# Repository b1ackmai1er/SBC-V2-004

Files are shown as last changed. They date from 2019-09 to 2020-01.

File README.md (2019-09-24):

# SBC-V2-004
 Retrobrew Computers SBC-V2 development

 Updated design to include the following changes.

    Correction of reset circuit.
    Addition of speaker circuit.
    Add solder jumpers for bypassing DS1210.
    Move status LED to corner of board as per other ECB boards.
    Align serial connector pinout and functionality to SBC Z180 Mark IV
    Add max232 solder jumpers for TTL level output.
    Add onboard super capacitor.
    Incorporate ppide.
    Update to Kicad 5.
    Add jumper settings to silkscreen.
    Move reset switch to edge of board and remove reset jumper.
    Add jumpers to configure battery backup source.
    Add cpu clock divider to support MSX.
    Default to hard Kontron reset mode.

Other ideas to be considered:

    RAM access over ECB-BUS.
    Renumber all parts.

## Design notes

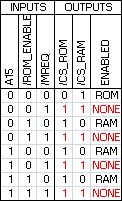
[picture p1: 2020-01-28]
logic.png

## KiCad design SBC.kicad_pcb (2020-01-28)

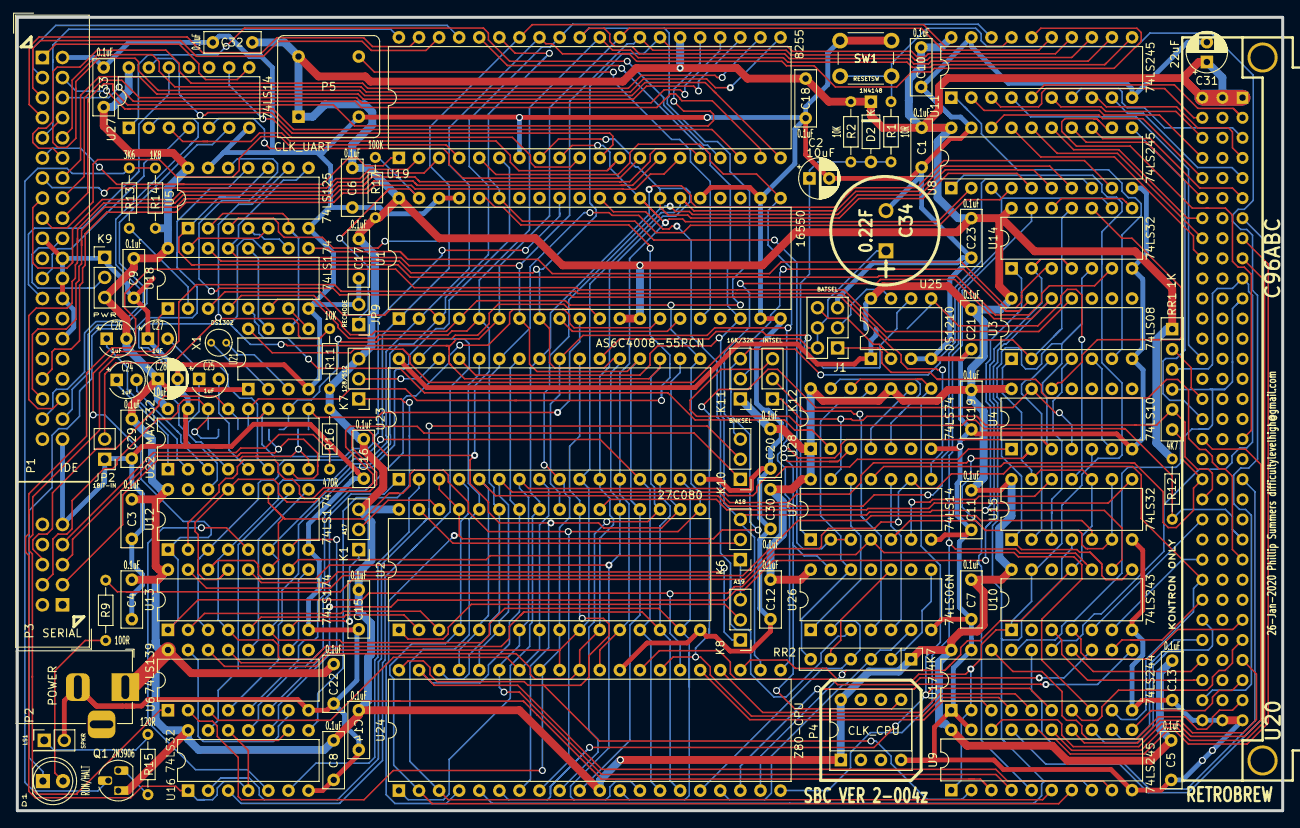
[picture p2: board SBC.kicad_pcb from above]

Board: 2 copper layers, 160.0 x 100.3 mm, 102 parts (0 on the bottom side), 203 nets.

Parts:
C1, C3, C4, C5, C6, C7, C8, C9, C10, C11, C12, C13, C14, C15, C16, C17, C18, C19, C20, C21, C22, C23, C29, C30, C32, C33: 0.1uF; C_Disc_D7.0mm_W2.5mm_P5.00mm
C2, C28: 10uF; CP_Radial_D5.0mm_P2.50mm
C24, C25, C26, C27: 1uF; CP_Radial_Tantal_D4.5mm_P2.50mm
C31: 22uF; CP_Radial_D5.0mm_P2.50mm
C34: 0.22F; SuperCap5
D1: RUN/HALT; LED_D5.0mm
D2: 1N4148; D_DO-35_SOD27_P7.62mm_Horizontal
J1: BATSEL; PinHeader_2x03_P2.54mm_Vertical
JP2: 1BIT-IN; PinHeader_1x02_P2.54mm_Vertical
JP3: RAMVCC; SolderJumper-2_P1.3mm_Open_RoundedPad1.0x1.5mm
JP4: RAMCS; SolderJumper-2_P1.3mm_Open_RoundedPad1.0x1.5mm
JP5: RXD; SolderJumper-2_P1.3mm_Open_RoundedPad1.0x1.5mm
JP6: CTS; SolderJumper-2_P1.3mm_Open_RoundedPad1.0x1.5mm
JP7: TXD; SolderJumper-2_P1.3mm_Open_RoundedPad1.0x1.5mm
JP8: RTS; SolderJumper-2_P1.3mm_Open_RoundedPad1.0x1.5mm
JP9: RECMODE; PinHeader_1x02_P2.54mm_Vertical
K1: A17; PinHeader_1x03_P2.54mm_Vertical
K6: A18; PinHeader_1x03_P2.54mm_Vertical
K7: 128/512; PinHeader_1x03_P2.54mm_Vertical
K8: A19; PinHeader_1x03_P2.54mm_Vertical
K9: PWR; PinHeader_1x03_P2.54mm_Vertical
K10: BNKSEL; PinHeader_1x03_P2.54mm_Vertical
K11: 16K/32K; PinHeader_1x03_P2.54mm_Vertical
K12: INTSEL; PinHeader_1x03_P2.54mm_Vertical
LS1: SPKR; PinHeader_2x01_P2.54mm_Vertical
P1: IDE; IDC-Header_2x20_P2.54mm_Vertical
P2: POWER; BarrelJack_Horizontal
P3: SERIAL; IDC-Header_2x05_P2.54mm_Vertical
P4: CLK_CPU; DIP-8_W7.62mm_Socket
P5: CLK_UART; Oscillator_DIP-8
Q1: 2N3906; TO-92_HandSolder
R1: 10R; R_Axial_DIN0204_L3.6mm_D1.6mm_P7.62mm_Horizontal
R2, R11: 10K; R_Axial_DIN0204_L3.6mm_D1.6mm_P7.62mm_Horizontal
R9: 100R; R_Axial_DIN0204_L3.6mm_D1.6mm_P7.62mm_Horizontal
R12: 4K7; R_Axial_DIN0204_L3.6mm_D1.6mm_P7.62mm_Horizontal
R13: 3K6; R_Axial_DIN0204_L3.6mm_D1.6mm_P7.62mm_Horizontal
R14: 1K8; R_Axial_DIN0204_L3.6mm_D1.6mm_P7.62mm_Horizontal
R15: 120R; R_Axial_DIN0204_L3.6mm_D1.6mm_P7.62mm_Horizontal
R16: 470R; R_Axial_DIN0204_L3.6mm_D1.6mm_P7.62mm_Horizontal
R17: 100K; R_Axial_DIN0204_L3.6mm_D1.6mm_P7.62mm_Horizontal
RR1: 1K; R_Array_SIP6
RR2: 4K7; R_Array_SIP6
SW1: RESETSW; SW_PUSH_6mm_H8mm
U1: 16550; DIP-40_W15.24mm
U2: 27C080; DIP-32_W15.24mm
U3: 74LS08; DIP-14_W7.62mm
U4: 74LS10; DIP-14_W7.62mm
U5: 74LS125; DIP-14_W7.62mm
U6: 74LS139; DIP-16_W7.62mm
U7, U27: 74LS14; DIP-14_W7.62mm
U8, U9, U11: 74LS245; DIP-20_W7.62mm
U10: 74LS243; DIP-14_W7.62mm
U12, U13, U18: 74LS174; DIP-16_W7.62mm
U14, U15, U16: 74LS32; DIP-14_W7.62mm
U17: 74LS244; DIP-20_W7.62mm
U19: 8255; DIP-40_W15.24mm
U20: C96ABC; C96ABCMC
U21: DS1302; DIP-8_W7.62mm
U22: MAX232; DIP-16_W7.62mm
U23: AS6C4008-55PCN; DIP-32_W15.24mm
U24: Z80-CPU; DIP-40_W15.24mm
U25: DS1210; DIP-8_W7.62mm
U26: 74LS06N; DIP-14_W7.62mm
U28: 74LS74; DIP-14_W7.62mm
X1: CRYSTAL; Crystal_Round_D3.0mm_Vertical

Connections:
/-PC3: P1.37, U27.2
/-PC4: P1.38, U27.6
/-PC5: P1.23, U27.4
/-PC6: P1.25, U27.12
/-PC7: P1.1, U27.8
//BUSAK: U4.5, U8.1, U9.1, U10.1, U10.13, U17.2, U24.23
//BUSRQ: U17.3, U24.25
//CS_CFG: U6.7, U6.15
//CS_CFG1: U6.12, U12.9
//CS_CFG2: U6.10, U13.9
//CS_PPI: U6.4, U19.6
//CS_RAM: JP4.1, U15.11, U25.5
//CS_ROM: U2.22, U15.8
//CS_RTC: U6.6, U14.2, U14.4
//CS_UART: U1.14, U6.5
//HALT: U17.11, U24.18
//INT: RR2.4, U24.16, U26.2
//IORQ: U10.10, U14.13, U24.20
//IOSEL: U3.2, U6.1, U14.11
//M1: U4.4, U4.13, U17.4, U24.27
//MREQ: U3.1, U10.11, U15.10, U15.13, U24.19
//NMI: RR2.3, U24.17, U26.6
//RD: U1.21, U2.24, U4.3, U10.8, U14.5, U15.1, U19.5, U23.24, U24.21
//RESET: U7.4, U12.1, U13.1, U17.8, U18.1, U24.26
//RESET_IN: R1.2, SW1.2, U20.C31
//RFSH: U17.13, U24.28
//ROM_ENABLE: U13.15, U15.5
//RTC_RD: U5.1, U5.10, U14.6
//RTC_WR: U14.3, U18.9
//WAIT: U17.5, U24.24
//WR: K6.3, U1.18, U10.9, U14.1, U19.36, U23.29, U24.22
/A0: U1.28, U2.12, U8.2, U19.9, U23.12, U24.30
/A1: U1.27, U2.11, U6.14, U8.5, U19.8, U23.11, U24.31
/A2: U1.26, U2.10, U6.13, U8.7, U23.10, U24.32
/A3: U2.9, U6.2, U8.6, U23.9, U24.33
/A4: U2.8, U6.3, U9.3, U23.8, U24.34
/A5: U2.7, U4.1, U9.4, U23.7, U24.35
/A6: U2.6, U4.2, U9.5, U23.6, U24.36
/A7: U2.5, U8.3, U14.9, U23.5, U24.37
/A8: U2.27, U8.4, U23.27, U24.38
/A9: U2.26, U9.9, U23.26, U24.39
/A10: U2.23, U9.2, U23.23, U24.40
/A11: U2.25, U8.9, U23.25, U24.1
/A12: U2.4, U9.7, U23.4, U24.2
/A13: U2.28, U9.6, U23.28, U24.3
/A14: K11.3, U2.29, U8.8, U23.3, U24.4
/A15: K10.3, U3.12, U9.8, U15.4, U24.5
/A15_RAM: U16.3, U23.31
/A15_ROM: U2.3, U13.2
/A16_RAM: U16.6, U23.2
/A16_ROM: U2.2, U13.5
/A17_RAM: K7.1, U16.8
/A17_ROM: K1.1, U13.7
/A18_RAM: U16.11, U23.1
/A18_ROM: K6.1, K8.3, U13.10
/A19_ROM: K8.1, U13.12
/BUF_Q4: U18.7, U21.5
/BUF_Q5: U5.4, U18.10
/BUF_Q6: U18.12, U21.7
/BUF_Q7: U5.5, U18.15
/B_/BUSAK: U17.18, U20.A31
/B_/BUSRQ: RR1.4, U17.17, U20.A11
/B_/HALT: R9.2, U7.9, U17.9, U20.C25
/B_/IEO: RR1.2, U20.C16
/B_/INT: K12.1, RR1.5, U7.13, U20.C21
/B_/IORQ: U10.4, U20.A27
/B_/M1: U17.16, U20.A20
/B_/MREQ: U10.3, U20.C30
/B_/NMI: RR1.6, U7.11, U20.C20
/B_/RD: U10.6, U20.C24
/B_/RESOUT: U17.12, U20.C26
/B_/RFSH: U17.7, U20.A28
/B_/WAIT: RR1.3, U17.15, U20.A10
/B_/WR: U10.5, U20.C22
/B_A0: U8.18, U20.C5
/B_A1: U8.15, U20.C7
/B_A2: U8.13, U20.A6
/B_A3: U8.14, U20.C6
/B_A4: U9.17, U20.A7
/B_A5: U9.16, U20.A8
/B_A6: U9.15, U20.A9
/B_A7: U8.17, U20.C9
/B_A8: U8.16, U20.C8
/B_A9: U9.11, U20.A30
/B_A10: U9.18, U20.C18
/B_A11: U8.11, U20.C17
/B_A12: U9.13, U20.C27
/B_A13: U9.14, U20.A29
/B_A14: U8.12, U20.A18
/B_A15: U9.12, U20.C28
/B_BAT: J1.1, U20.A24
/B_CLK_CPU: U17.14, U20.C29
/B_D0: U11.3, U20.C2
/B_D1: U11.4, U20.C14
/B_D2: U11.2, U20.C4
/B_D3: U11.8, U20.A4
/B_D4: U11.9, U20.A5
/B_D5: U11.5, U20.A2
/B_D6: U11.7, U20.A3
/B_D7: U11.6, U20.C3
/CFG1_Q0: K10.1, U12.2
/CFG1_Q1: U12.5, U16.5
/CFG1_Q2: U12.7, U16.10
/CFG1_Q3: U12.10, U16.13
/CLKSEL: U18.5, U28.2
/CLK_CPU: U17.6, U24.6, U28.8, U28.12
/CLK_UART: P5.5, U1.16
/CTS: JP6.2, P3.6, U22.13
/CTS_TTL: JP6.1, U1.36, U22.12
/D0: U1.1, U2.13, U5.3, U11.17, U12.3, U13.3, U19.34, U23.13, U24.14
/D1: U1.2, U2.14, U11.16, U12.4, U13.4, U19.33, U23.14, U24.15
/D2: U1.3, U2.15, U11.18, U12.6, U13.6, U18.3, U19.32, U23.15, U24.12
/D3: U1.4, U2.17, U11.12, U12.11, U13.11, U18.4, U19.31, U23.17, U24.8
/D4: U1.5, U2.18, U11.11, U12.13, U13.13, U18.6, U19.30, U23.18, U24.7
/D5: U1.6, U2.19, U11.15, U12.14, U18.11, U19.29, U23.19, U24.9
/D6: U1.7, U2.20, U5.8, U11.13, U18.13, U19.28, U23.20, U24.10
/D7: U1.8, U2.21, U11.14, U13.14, U18.14, U19.27, U23.21, U24.13
/DATA_DIR: U3.6, U11.1
/DTR: P3.7, R16.2
/INT: U1.30, U26.3
/PA0: P1.17, U19.4
/PA1: P1.15, U19.3
/PA2: P1.13, U19.2
/PA3: P1.11, U19.1
/PA4: P1.9, U19.40
/PA5: P1.7, U19.39
/PA6: P1.5, U19.38
/PA7: P1.3, U19.37
/PB0: P1.4, U19.18
/PB1: P1.6, U19.19
/PB2: P1.8, U19.20
/PB3: P1.10, U19.21
/PB4: P1.12, U19.22
/PB5: P1.14, U19.23
/PB6: P1.16, U19.24
/PB7: P1.18, U19.25
/PC0: P1.35, U19.14
/PC1: P1.33, U19.15
/PC2: P1.36, U19.16
/PC3: U19.17, U27.1
/PC4: U19.13, U27.5
/PC5: U19.12, U27.3
/PC6: U19.11, U27.13
/PC7: U19.10, U27.9
/PU4K7-A: RR2.2, U26.8
/PU4K7-B: RR2.5, U26.10
/PU4K7-C: RR2.6, U26.12, U28.11
/RESET: U1.35, U7.2, U7.3, U19.35
/RTC_DQ: U5.2, U5.6, U21.6
/RTS: JP8.2, P3.4, U22.14
/RTS_TTL: JP8.1, U1.32, U22.11
/RX: JP5.2, P3.3, U22.8
/SIN_TTL: JP5.1, U1.10, U22.9
/SOUT_TTL: JP7.1, U1.11, U22.10
/TX: JP7.2, P3.5, U22.7
/VBAT1: J1.6, U25.2
/VBAT2: J1.3, U25.7
/VCC_SRAM: JP3.2, U23.32, U25.1
/~B_IQ0: K12.3, R12.2, U20.A23
GND: C1.2, C2.2, C3.2, C4.2, C5.2, C6.2, C7.2, C8.2, C9.2, C10.2, C11.2, C12.2, C13.2, C14.2, C15.2, C16.2, C17.2, C18.2, C19.2, C20.2, C21.2, C22.2, C23.2, C27.1, C28.2, C29.2, C30.2, C31.2, C32.2, C33.2, C34.2, J1.5, JP2.1, JP9.2, K9.1, LS1.2, P1.2, P1.19, P1.22, P1.24, P1.26, P1.30, P1.40, P2.2, P3.9, P4.4, P5.4, SW1.1, U1.19, U1.20, U1.22, U1.25, U1.37, U1.38, U2.16, U3.7, U4.7, U5.7, U5.13, U6.8, U7.7, U8.10, U8.19, U9.10, U9.19, U10.7, U11.10, U11.19, U12.8, U13.8, U14.7, U15.7, U16.7, U17.1, U17.10, U17.19, U18.8, U19.7, U20.A32, U20.B32, U20.C32, U21.4, U22.15, U23.16, U24.29, U25.3, U25.4, U26.7, U27.7, U28.7
unnamed: C2.1, D2.2, R1.1, R2.2, U7.1
unnamed: C24.1, U22.1
unnamed: C24.2, U22.3
unnamed: C25.1, U22.4
unnamed: C25.2, U22.5
unnamed: C26.1, U22.2
unnamed: C27.2, U22.6
unnamed: C34.1, J1.2, J1.4, U21.8
unnamed: D1.1, U5.11
unnamed: D1.2, R9.1
unnamed: JP2.2, R11.2, U5.9
unnamed: JP4.2, U23.22, U25.6
unnamed: JP9.1, R17.1, U1.39
unnamed: K1.2, U2.30
unnamed: K6.2, U2.31
unnamed: K7.2, U23.30
unnamed: K8.2, U2.1
unnamed: K9.2, P1.20
unnamed: K10.2, U16.2
unnamed: K11.2, U3.13
unnamed: K12.2, U26.4
unnamed: LS1.1, R15.1
unnamed: P4.5, U26.13, U28.3
unnamed: Q1.2, R13.1, R14.1
unnamed: Q1.3, R15.2
unnamed: R13.2, U18.2
unnamed: U1.9, U1.15
unnamed: U3.5, U4.6
unnamed: U5.12, U7.8
unnamed: U4.12, U14.10
unnamed: U14.8, U14.12
unnamed: U3.3, U15.2
unnamed: U3.4, U15.3
unnamed: U7.5, U15.6, U15.9
unnamed: U7.6, U15.12
unnamed: U3.11, U16.1, U16.4, U16.9, U16.12
unnamed: U21.2, X1.2
unnamed: U21.3, X1.1
unnamed: U7.12, U26.1
unnamed: U7.10, U26.5
unnamed: U28.4, U28.9
unnamed: U28.5, U28.13
VCC: C1.1, C3.1, C4.1, C5.1, C6.1, C7.1, C8.1, C9.1, C10.1, C11.1, C12.1, C13.1, C14.1, C15.1, C16.1, C17.1, C18.1, C19.1, C20.1, C21.1, C22.1, C23.1, C26.2, C28.1, C29.1, C30.1, C31.1, C32.1, C33.1, D2.1, JP3.1, K1.3, K7.3, K9.3, K11.1, P2.1, P4.1, P4.8, P5.1, P5.8, Q1.1, R2.1, R11.1, R12.1, R14.2, R16.1, R17.2, RR1.1, RR2.1, U1.12, U1.13, U1.40, U2.32, U3.14, U4.14, U5.14, U6.16, U7.14, U8.20, U9.20, U10.14, U11.20, U12.16, U13.16, U14.14, U15.14, U16.14, U17.20, U18.16, U19.26, U20.A1, U20.B1, U20.C1, U21.1, U22.16, U24.11, U25.8, U26.14, U27.14, U28.1, U28.10, U28.14

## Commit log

2019-09-24 Version B
    [SBC.kicad_pcb, SBC.sch]
2019-09-24 Version C
    [SBC-2019-01-16-20-46-51.sch, SBC.kicad_pcb, SBC.sch]
2019-09-24 Version D
    [SBC.kicad_pcb, SBC.sch]
2019-09-24 Version E
    [SBC.kicad_pcb, SBC.sch]
2019-09-24 Version F
    [SBC.kicad_pcb, SBC.sch]
2019-09-24 Version G
    [SBC.kicad_pcb, SBC.sch]
2019-09-24 Version H
    [SBC.kicad_pcb]
2019-09-24 Version I
    [SBC.kicad_pcb, SBC.sch]
2019-09-24 Version J
    [SBC.kicad_pcb, SBC.sch]
2019-09-24 Version K
    [SBC.kicad_pcb, SBC.sch]
2019-09-24 Version L
    [SBC.kicad_pcb, SBC.sch]
2019-09-24 Version M
    [SBC.kicad_pcb]
2019-09-24 Version N
    [SBC.kicad_pcb, SBC.sch]
2019-09-24 Version O
    [SBC.kicad_pcb, SBC.sch]
2019-09-24 Version P
    [SBC.kicad_pcb, SBC.sch]
2019-09-24 Version Q
    [SBC-B.Mask.gbs, SBC-B.SilkS.gbo, SBC-Component.gtl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]
2019-09-24 Version R
    [SBC-B.Mask.gbs, SBC-B.SilkS.gbo, SBC-Component.gtl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]
2019-09-24 Version S
    [SBC.kicad_pcb, SBC.sch]
2019-09-24 Version T
    [SBC.kicad_pcb, SBC.sch]
2019-09-24 Version U
    [SBC.kicad_pcb, SBC.sch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]
2019-09-24 Version V
    [SBC.kicad_pcb, SBC.sch]
2019-09-24 Version W
    [SBC.kicad_pcb, SBC.sch]
2019-09-24 Version X
    [SBC.kicad_pcb, SBC.sch]
2020-01-28 Version Y
    [SBC.kicad_pcb]
2020-01-28 Version Z
    [SBC.kicad_pcb, SBC.sch]
